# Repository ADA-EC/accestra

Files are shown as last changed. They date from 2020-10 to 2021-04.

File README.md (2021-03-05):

# Accestra
 Sistema de entrada/saída de membros na sala da ADA.

<h2> Descrição </h2>

O objetivo é desenvolver e instalar um sistema de abertura da porta por meio dos cartões USP, a partir da comunicação em rádio frequência (RFID).
  
<h2> Tencologias Usadas </h2>

Para compor o sistema de acesso, foi utilizado um Arduino UNO, com planos de usarmos apenas o <b>ATmega</b>. A porta é equipada com um <b>leitor de RFID</b> e um <b>botão</b> interno, enquanto a tranca será substituída por uma <b>fechadura elétrica</b> comum, acionada por um sinal elétrico enviado pelo sistema. Haverá ainda um <b>buzzer</b> para alertas sonoros e um <b>LED vermelho e outro verde</b> para indicação do estado.<br><br>
Na programação foram utilizadas as bibliotecas <b>SPI</b> e <b>MFRC522</b>

<h2> Protótipo </h2>

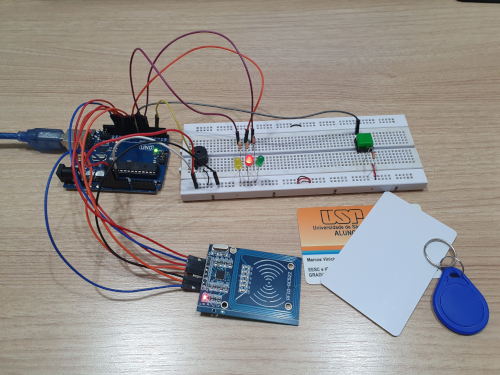
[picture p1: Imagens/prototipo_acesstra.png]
aaa


<h2> Manual do Sistema </h2>

Um manual do sistema, contendo informações detalhadas sobre o código e sobre como operar estará disponível neste repostório 

<h2>Membros</h2>
<ul>
 <li>Érika Hortência</li>
 <li>Fernando Rosalini Calaza</li>
 <li>Marcos Pietrucci</li>
</ul>
<h2>Agradecimentos</h2>
<ul>
 <li>Alexandre Batistella Bellas</li>
 <li>Bruno Coulturato pelas contribuições no desenvolvimento da PCB</li>

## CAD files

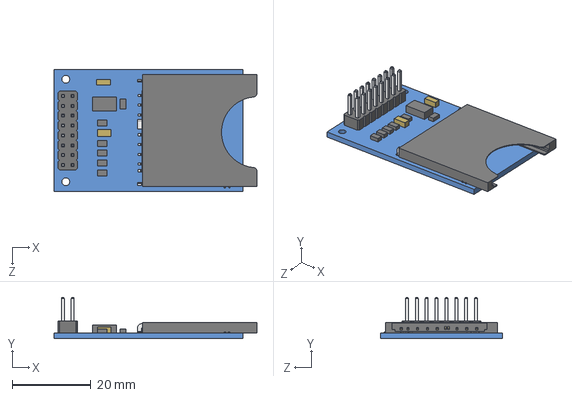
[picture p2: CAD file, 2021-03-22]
PCB/Componentes 3D/SD Card Module Arduino.STEP
51.5 x 10.5 x 31.0 mm
SD Card Module-part
SD socket

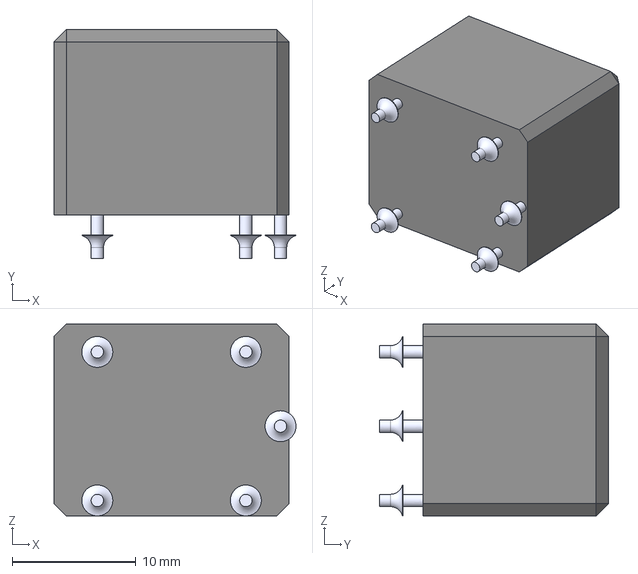
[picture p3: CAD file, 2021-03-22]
PCB/Componentes 3D/Relais HLS8L-DC3V-S-C.step
19.5 x 18.5 x 15.5 mm

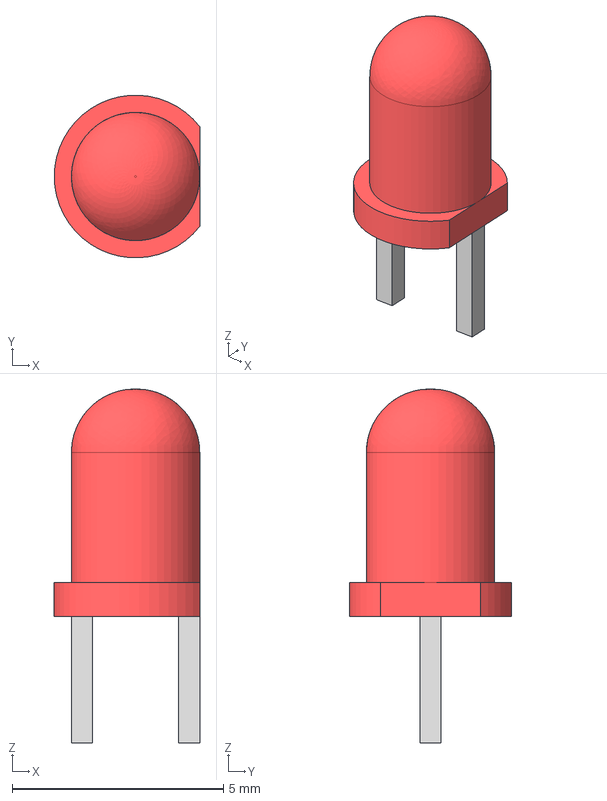
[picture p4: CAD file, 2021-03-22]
PCB/Componentes 3D/LED 3mm Red 3mm Leads.step
3.45 x 3.85 x 8.38 mm
LEDBody
Lead1Body
Lead2Body

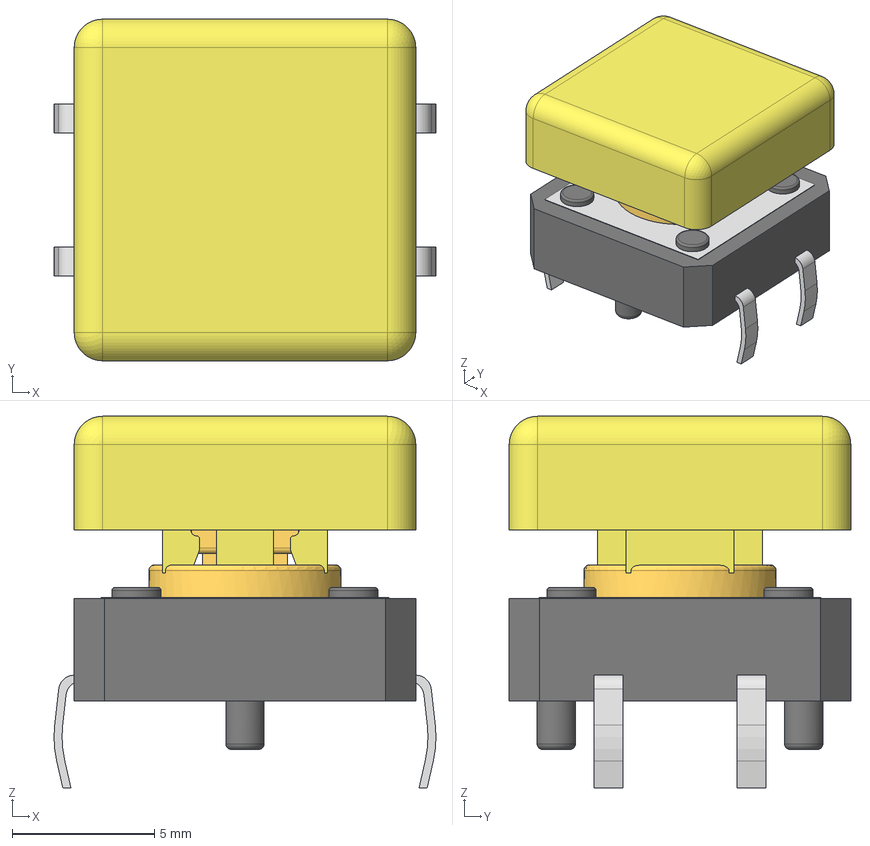
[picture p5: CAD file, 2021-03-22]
PCB/Componentes 3D/botao.stp
13.4 x 12.0 x 13.0 mm

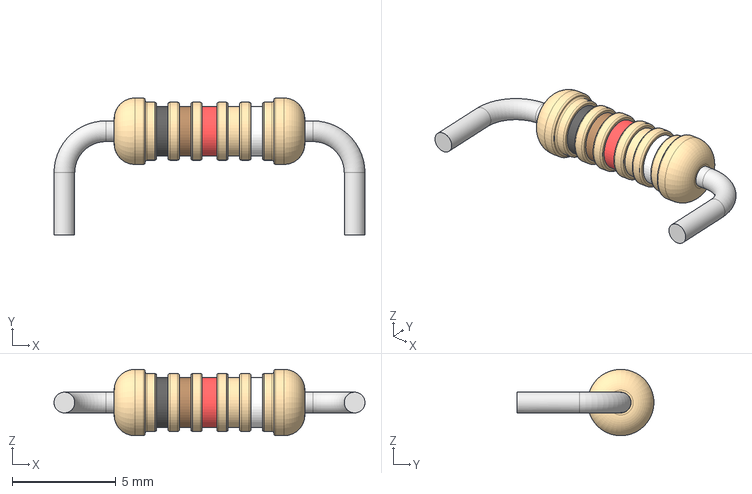
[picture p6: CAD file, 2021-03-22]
PCB/Componentes 3D/Resistor.step
15.0 x 6.60 x 3.20 mm

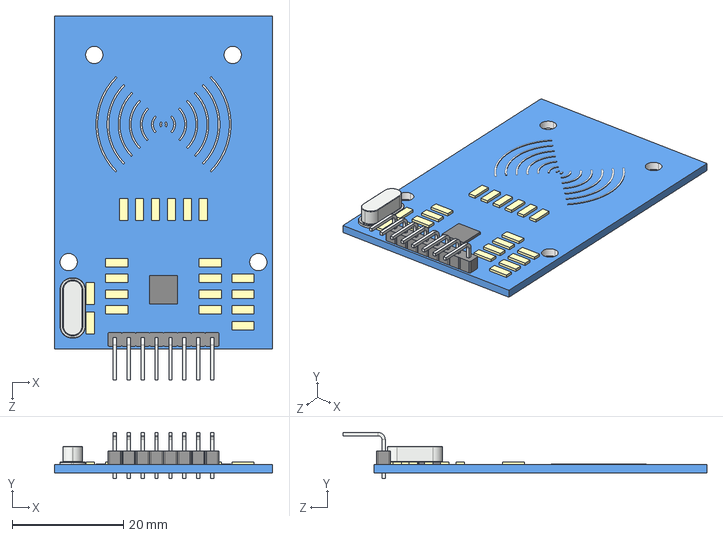
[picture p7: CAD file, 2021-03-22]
PCB/Componentes 3D/RC522.STEP
39.2 x 8.30 x 65.5 mm

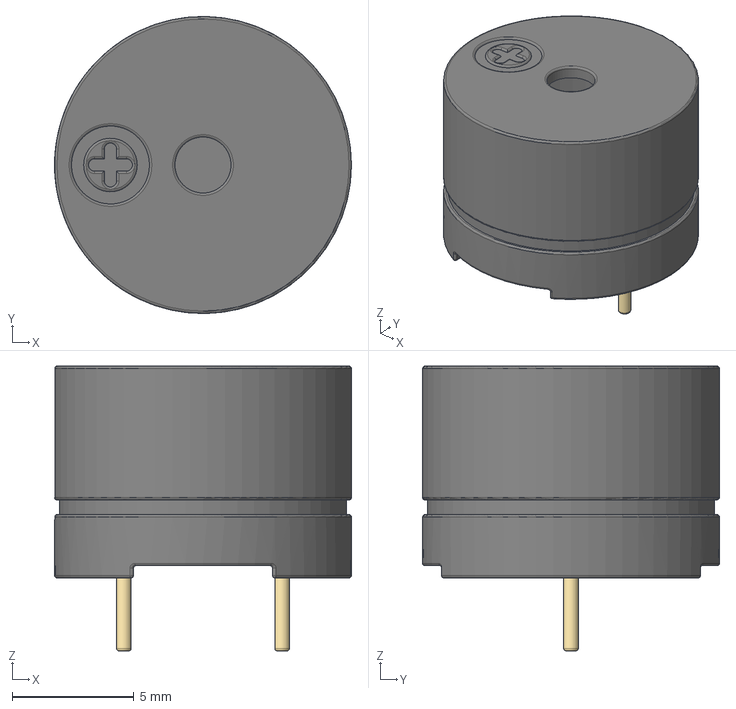
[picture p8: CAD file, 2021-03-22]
PCB/Componentes 3D/buzzer.stp
12.2 x 12.2 x 11.7 mm

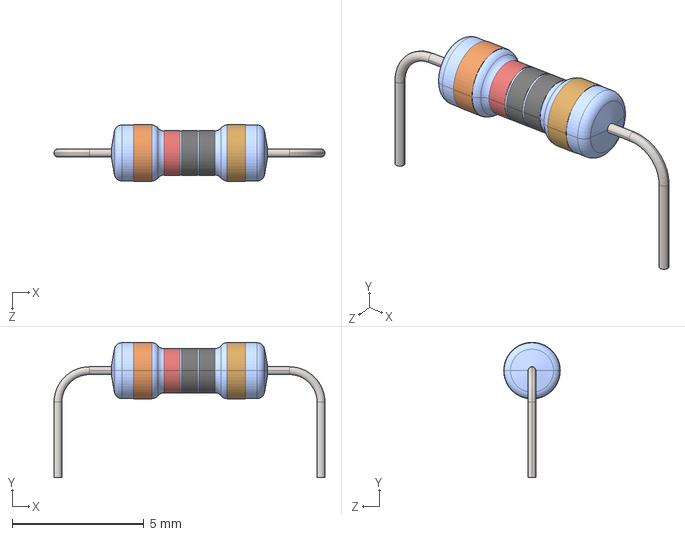
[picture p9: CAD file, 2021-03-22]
PCB/Componentes 3D/axial resistor 6mm.STEP
10.3 x 5.14 x 2.15 mm

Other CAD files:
PCB/Componentes 3D/NanoV3 v4.f3d

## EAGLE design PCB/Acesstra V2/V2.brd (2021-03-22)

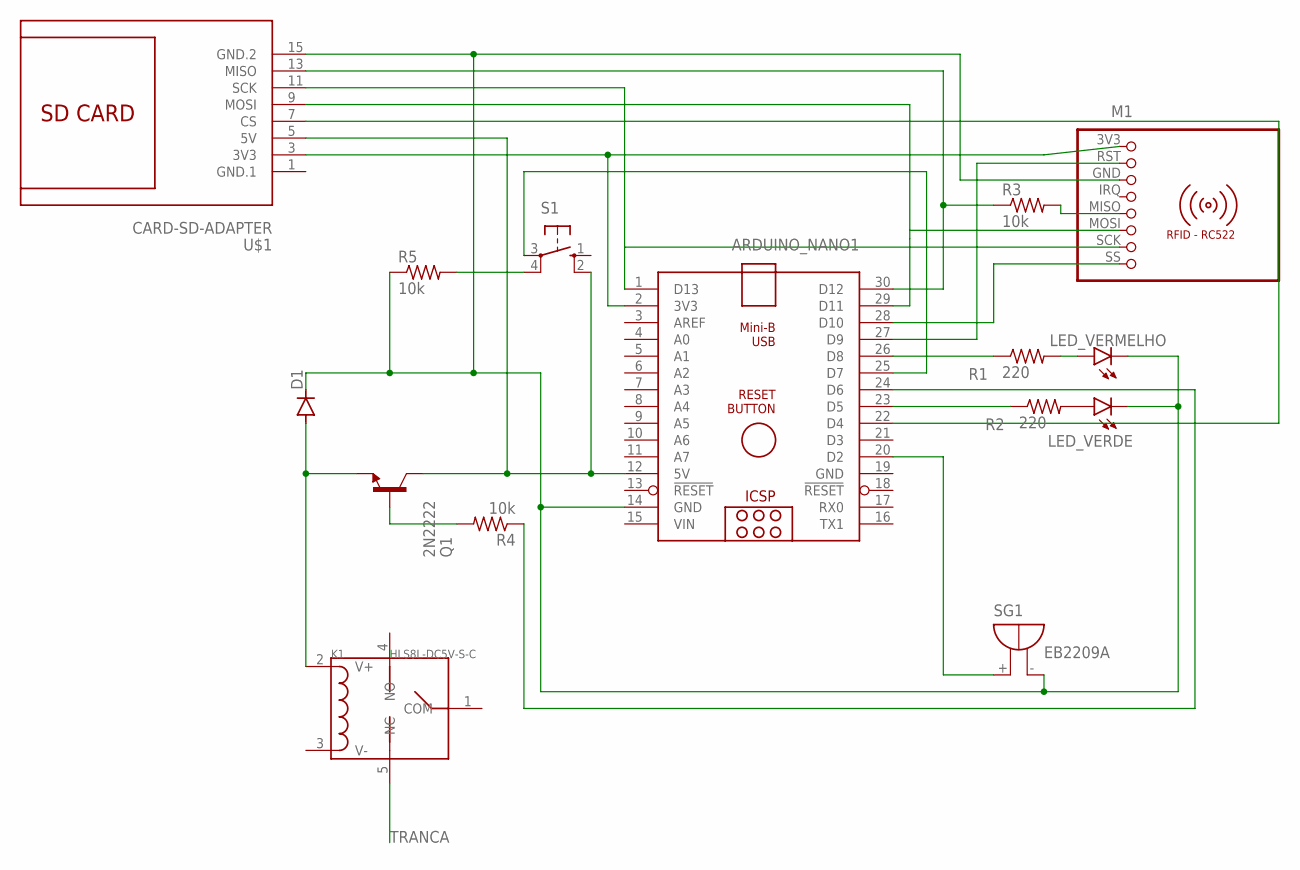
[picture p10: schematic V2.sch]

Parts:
ARDUINO_NANO1: ARDUINO_NANO
D1: 1N4148DO35-10; DO35-10
K1: HLS8L-DC5V-S-C; REY5-19.0X15.0X15.0MM
LED_VERDE: -LED; LED5
LED_VERMELHO: -LED; LED5
M1: RFID-RC522
Q1: 2N2222; TO92-CBE
R1, R2: 220; 0204/5
R3, R4, R5: 10k; 0204/5
S1: 10-XX; B3F-10XX
SG1: EB2209A
U$1: CARD-SD-ADAPTER

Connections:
GND: ARDUINO_NANO1.19 (GND)
GND.1: U$1.1 (GND.1)
unnamed: ARDUINO_NANO1.20 (D2), SG1.+
unnamed: LED_VERMELHO.ANODE, R1.2
unnamed: LED_VERDE.ANODE, R2.2
unnamed: ARDUINO_NANO1.26 (D8), R1.1
unnamed: ARDUINO_NANO1.23 (D5), R2.1
unnamed: ARDUINO_NANO1.24 (D6), R4.1
unnamed: D1.A, K1.2 (V+), Q1.E
unnamed: Q1.B, R4.2
unnamed: ARDUINO_NANO1.14 (GND), D1.C, LED_VERDE.CATHODE, LED_VERMELHO.CATHODE, M1.GND (3), R5.1, SG1.-, U$1.15 (GND.2)
unnamed: ARDUINO_NANO1.12 (5V), Q1.C, S1.2 (S1), U$1.5 (5V)
unnamed: ARDUINO_NANO1.25 (D7), S1.3
unnamed: ARDUINO_NANO1.2 (3V3), M1.3V3 (1), U$1.3 (3V3)
unnamed: R5.2, S1.4 (P1)
unnamed: ARDUINO_NANO1.27 (D9), M1.RST (2)
unnamed: M1.MISO (5), R3.2
unnamed: ARDUINO_NANO1.30 (D12), R3.1, U$1.13 (MISO)
unnamed: ARDUINO_NANO1.29 (D11), M1.MOSI (6), U$1.9 (MOSI)
unnamed: ARDUINO_NANO1.22 (D4), U$1.7 (CS)
unnamed: ARDUINO_NANO1.28 (D10), M1.SS (8)
unnamed: ARDUINO_NANO1.1 (D13), M1.SCK (7), U$1.11 (SCK)
TRANCA: K1.5 (NC)
VIN: ARDUINO_NANO1.15 (VIN)

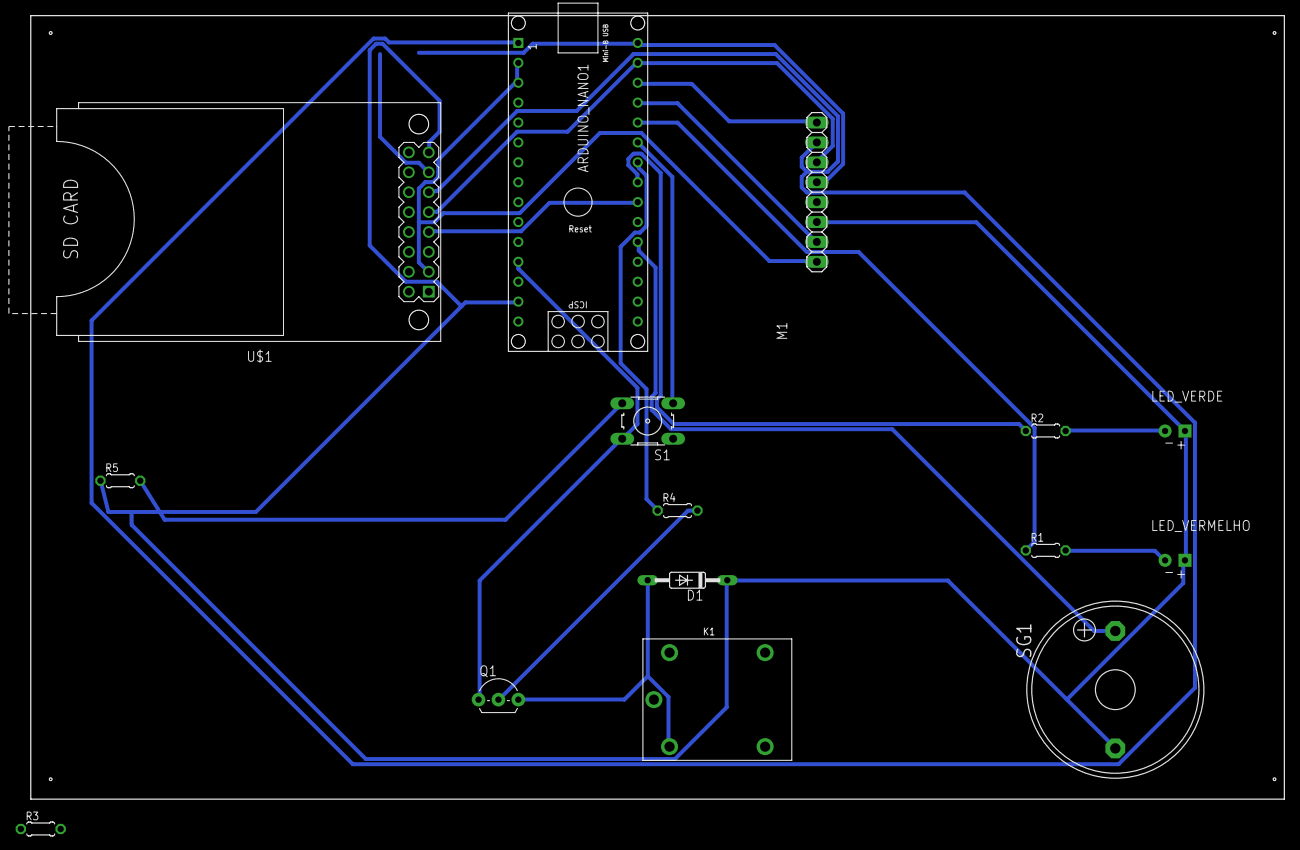
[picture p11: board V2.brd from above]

Board: 2 copper layers, 160.0 x 100.0 mm, 15 parts (0 on the bottom side), 20 nets.

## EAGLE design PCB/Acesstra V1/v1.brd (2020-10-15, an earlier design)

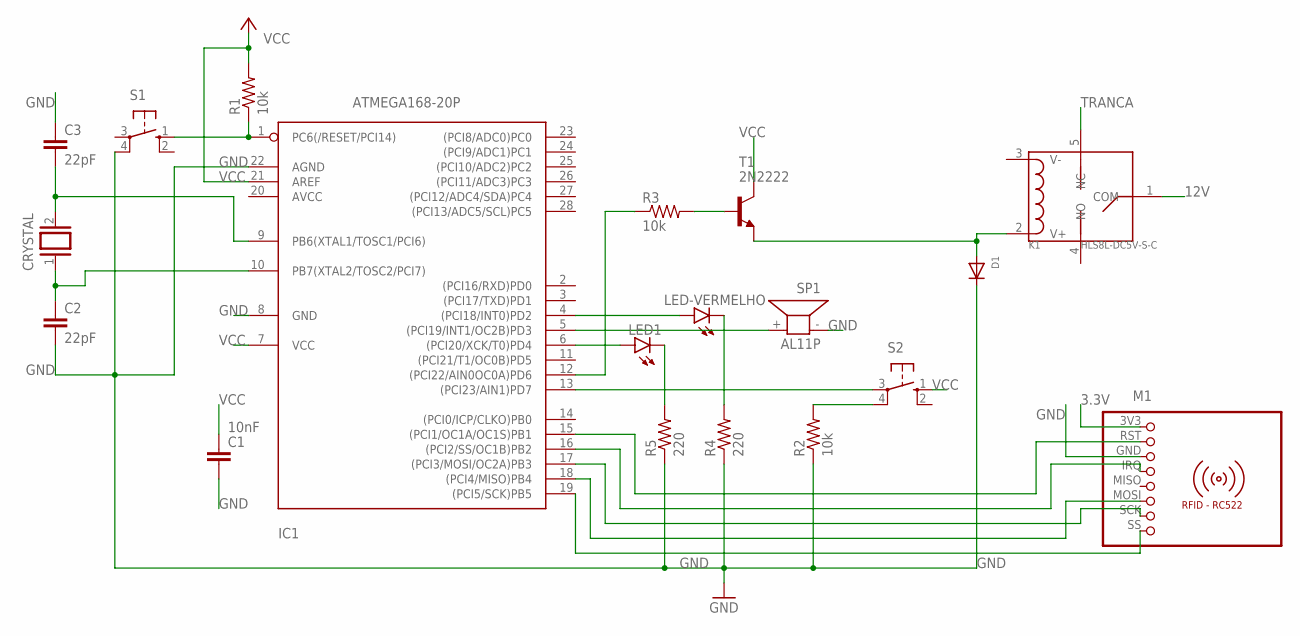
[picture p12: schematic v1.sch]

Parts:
C1: 10nF; C025-025X050
C2, C3: 22pF; C025-025X050
CRYSTAL: XTAL/S; QS
D1: DIODEDO-1N4148; DO-1N4148
IC1: ATMEGA168-20P; DIL28-3
K1: HLS8L-DC5V-S-C; REY5-19.0X15.0X15.0MM
LED1: LED5MM
LED-VERMELHO: LED5MM
M1: RFID-RC522
R1, R2, R3: 10k; 0204/7
R4, R5: 220; 0204/7
S1, S2: 10-XX; B3F-10XX
SP1: AL11P
T1: 2N2222; TO92-EBC-OVAL

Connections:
3.3V: M1.3V3 (1)
12V: K1.1 (COM)
GND: C1.2, C2.2, C3.1, D1.C, IC1.8 (GND), IC1.22 (AGND), M1.GND (3), R2.1, R4.1, R5.1, S1.4 (P1), SP1.- (1)
unnamed: IC1.1 (PC6(/RESET/PCI14)), R1.1, S1.1 (S)
unnamed: IC1.4 ((PCI18/INT0)PD2), LED-VERMELHO.A
unnamed: LED-VERMELHO.K (C), R4.2
unnamed: IC1.6 ((PCI20/XCK/T0)PD4), LED1.A
unnamed: LED1.K (C), R5.2
unnamed: IC1.5 ((PCI19/INT1/OC2B)PD3), SP1.+ (2)
unnamed: IC1.13 ((PCI23/AIN1)PD7), S2.3
unnamed: R2.2, S2.4 (P1)
unnamed: IC1.12 ((PCI22/AIN0OC0A)PD6), R3.1
unnamed: R3.2, T1.B
unnamed: D1.A, K1.2 (V+), T1.E
unnamed: C3.2, CRYSTAL.2, IC1.9 (PB6(XTAL1/TOSC1/PCI6))
unnamed: C2.1, CRYSTAL.1, IC1.10 (PB7(XTAL2/TOSC2/PCI7))
unnamed: IC1.15 ((PCI1/OC1A/OC1S)PB1), M1.RST (2)
unnamed: IC1.16 ((PCI2/SS/OC1B)PB2), M1.IRQ (4)
unnamed: IC1.17 ((PCI3/MOSI/OC2A)PB3), M1.SCK (7)
unnamed: IC1.18 ((PCI4/MISO)PB4), M1.MOSI (6)
unnamed: IC1.19 ((PCI5/SCK)PB5), M1.SS (8)
TRANCA: K1.5 (NC)
VCC: C1.1, IC1.7 (VCC), IC1.21 (AREF), R1.2, S2.1 (S), T1.C

Board: 2 copper layers, 19 parts (0 on the bottom side), 20 nets, no tracks yet.

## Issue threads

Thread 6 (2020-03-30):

Mudar a lógica de acionamento dos botões

Marcos-Pietrucci, 2020-03-30:
Pull-UP/Down - Faz diferença para o consumo no ATmega

Marcos-Pietrucci, 2020-04-03:
@FernandoCalaza Você pode me ajudar nisso, se tiver tempo? Sinta-se livre pra criar uma branch e fazer um pull-request, ou simplesmente me explicar melhor aqui o que deve ser feito

Marcos-Pietrucci, 2021-01-09:
Após pesquisa, a lógica do botão foi alterada. A entrada digital do botão permanece em nível lógico baixo, e assim que é detectado nível lógico alto, é feita abertura da porta.

Poupa-se, assim, energia elétrica (apesar de ser uma quantidade bem pequena)

Closed 2021-01-09.

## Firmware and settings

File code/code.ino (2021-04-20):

#include <SPI.h>
#include <SD.h>
#include <MFRC522.h>
#define SS_SD           4  // Slave Select do cartão SD
#define SS_RFID         10 // Slave Select do RFID
#define RST_PIN         9  // Configurable, see typical pin layout above
#define led_verde       5  // Led que indica porta positivo
#define led_vermelho    8  // Led que indica porta negativo
#define porta           6  // Envia o sinal de abertura para a porta
#define but_in          7  // Botão interno que abre a porta
#define buzzerPin       2  // Pino do buzzer que emite alertas sonoros

// --- Objetos do RFID --- //
MFRC522 mfrc522(SS_RFID, RST_PIN);   // Create MFRC522 instance

// --- Objetos do SD --- //
File arquivo;

// Struct dos membros
typedef struct memb
{
  byte codigo[4];
}Membro;

//UID que será lido na loop
byte UID_loop[4];

//UID do cartão de cadastro
byte UID_cadastro[4] = {146, 129, 82, 28};

//UID do cartão de descadastro
byte UID_descadastro[4] = {0, 0, 0, 0};

//0 para fechado, 1 para aberto
int estado_porta = 0; 

//Emite alerta sonoro de positivo
void positivo()
{
  tone(buzzerPin, 440, 400);
  delay(200);
  noTone(buzzerPin);
  tone(buzzerPin, 523, 400);
  delay(400);
  noTone(buzzerPin);
}

//Emite alerta sonoro de negativo
void negativo()
{
  tone(buzzerPin, 440, 400);
  delay(200);
  noTone(buzzerPin);
  tone(buzzerPin, 349, 400);
  delay(400);
  noTone(buzzerPin);
}

//Ajusta os leds para o estado atual da porta
void ajusta_led() 
{
  //Se estiver fechado
  if (!estado_porta)
  {
    digitalWrite(led_verde, LOW);
    digitalWrite(led_vermelho, HIGH);
  }
  else  //Se estiver aberto
  {
    digitalWrite(led_verde, HIGH);
    digitalWrite(led_vermelho, LOW);
  }
}

//Função que abre a porta - envia sinal elétrico para a tranca
void abre_porta()
{
  //Ativar a trava elétrica
  digitalWrite(porta, HIGH); 
  
  //O melhor tempo de delay deve ser testado
  delay(300);                
  digitalWrite(porta, LOW); 

  //Alterar os Leds
  estado_porta = 1;
  ajusta_led();
  positivo();
  delay(1000);

  //Alterar os Leds
  estado_porta = 0;
  ajusta_led();
}

//Função que lê um cartão USP e o cadastra no SD
void cadastra_membro()
{
  //Importante para não recadastrar o próprio cartão admin
  delay(1000);
  
  int estado_led = HIGH;
  int i;

  //Enquanto ainda não aproximar o cartão
  while ( ! mfrc522.PICC_IsNewCardPresent() || ! mfrc522.PICC_ReadCardSerial())
  {
    digitalWrite(led_verde, estado_led);
    digitalWrite(led_vermelho, estado_led);

    //Blinkar o LED
    estado_led = !estado_led; 

    //Som para indicar estado de cadastro
    tone(buzzerPin, 349, 400);
    delay(100);
    tone(buzzerPin, 349, 400);
    noTone(buzzerPin);
    delay(300);
  }
  
  //***************** Bloco de detecção de cartões  ***********//
  byte UID_lido[4];
  MFRC522::PICC_Type piccType = mfrc522.PICC_GetType(mfrc522.uid.sak);

  //Verifica se o cartão é do tipo válido
  if (piccType != MFRC522::PICC_TYPE_MIFARE_MINI &&  
    piccType != MFRC522::PICC_TYPE_MIFARE_1K &&
    piccType != MFRC522::PICC_TYPE_MIFARE_4K) 
  {
    negativo();
    ajusta_led();
    return;
  }

  //Armazena o UID lido
  for (byte j = 0; j < 4; j++) {
    UID_lido[j] = mfrc522.uid.uidByte[j];
  }

  //Desativa o RFID e ativa o SD
  digitalWrite(SS_RFID, HIGH);
  digitalWrite(SS_SD, LOW);
  delay(3);
  
  //------------------ Inserir o novo membro no cartão SD --------/
  if (!SD.begin(SS_SD))
  {
    erro();
  }
  
  //Abre o arquivo de membros
  arquivo = SD.open("membros.bin", FILE_WRITE); 
  
  if (arquivo) 
  {
    //Escreve os 4 bytes do UID lido
    arquivo.write(UID_lido, 4);
    arquivo.close();
  } 
  else 
  {
    erro();
  }

  //Desativa o SD e ativa o RFID
  digitalWrite(SS_RFID, LOW);
  digitalWrite(SS_SD, HIGH);
  delay(3);
  
  ///***************** Fim do bloco de cadastro de membros *******/
  ajusta_led();
  delay(1500);
}

//Função que verifica se o UID lido corresponde a algum cadastrado
boolean busca_membro(byte *UID_lido)
{
  int i;
  Membro mem;

  //Desativa o RFID e ativa o SD
  digitalWrite(SS_RFID, HIGH);
  digitalWrite(SS_SD, LOW);
  delay(3);
  
  //Abre o arquivo de membros
  arquivo = SD.open("membros.bin", FILE_READ);
  
  if(!arquivo)
    erro();

  for(i = 0; i < arquivo.size() ; i += 4)
  {
    //Lê arquivo os bytes do cartão SD
    arquivo.read(mem.codigo, 4);

    //Compara o UID lido com o membro cadastrado
    if(memcmp(UID_lido, mem.codigo, 4) == 0)
    {
      return true;
    }
  } 

  //Desativa o SD e ativa o RFID
  digitalWrite(SS_RFID, LOW);
  digitalWrite(SS_SD, HIGH);
  delay(3);

  return false; 
}

//Função que lê um cartão e o descadastra caso encontre-o
void deleta_membro()
{
  delay(1000); //Importante para não recadastrar o próprio cartão admin
  int estado_led = HIGH;
  int i;
  
  //Enquanto ainda não aproximar o cartão
  while ( ! mfrc522.PICC_IsNewCardPresent() || ! mfrc522.PICC_ReadCardSerial())
  {
    digitalWrite(led_verde, estado_led);
    digitalWrite(led_vermelho, estado_led);
    
    //Blinkar o LED
    estado_led = !estado_led; 

    //Alerta sonoro de descadastro
    tone(buzzerPin, 349, 400);
    delay(100);
    tone(buzzerPin, 523, 400);
    noTone(buzzerPin);
    delay(300);
  }
  
  //***************** Bloco de detecção de cartões ***********//
  
  byte UID_lido[4];
  MFRC522::PICC_Type piccType = mfrc522.PICC_GetType(mfrc522.uid.sak);

  //Verifica se o cartão é do tipo válido
  if (piccType != MFRC522::PICC_TYPE_MIFARE_MINI &&  
    piccType != MFRC522::PICC_TYPE_MIFARE_1K &&
    piccType != MFRC522::PICC_TYPE_MIFARE_4K) 
  {
    negativo();
    ajusta_led();
    return;
  }

  //Armazena o UID lido
  for (byte j = 0; j < 4; j++) {
    UID_lido[j] = mfrc522.uid.uidByte[j];
  }

  //Ativa o SD e desativa o cartão RFID
  digitalWrite(SS_RFID, HIGH);
  digitalWrite(SS_SD, LOW);

  //---- Percorrer o cartão SD e deletar o membro lógicamente ---- //
  byte vetorNulo[4] = {0,0,0,0};
  int flag = 0;
  Membro mem;
 
  //Abre o arquivo de membros
  arquivo = SD.open("membros.bin", O_WRITE | O_READ);

  if(!arquivo)
    erro();

  for(i = 0; i < arquivo.size() ; i += 4)
  {
    //Lê arquivo os bytes do cartão SD
    arquivo.read(mem.codigo, 4);

    //Compara o UID lido com o membro cadastrado
    if(memcmp(UID_lido, mem.codigo, sizeof(UID_lido)) == 0)
    { 
      //Volta o ponteiro 4 bytes atrás
      arquivo.seek(arquivo.position() - 4);

      //Escreve valor nulo no registro
      arquivo.write(vetorNulo, 4);

      //Indica que houve o descadastro
      flag = 1;
      
      break;
    }
  }   
  
  arquivo.close();

  //Se não houve descadastro, emitir alerta negativo
  if(!flag)
  {
    negativo();
  }
  
  //Ativa o RFID e desativa o cartão SD
  digitalWrite(SS_RFID, LOW);
  digitalWrite(SS_SD, HIGH);

  ///***************** Fim do bloco de descadastro de membros *******/
  ajusta_led();
  delay(1500);
}

//Função que emite um alerta sonoro e visual de erro
void erro()
{
  //O usuário deve corrigir o problema e resetar o sistema
  digitalWrite(led_verde, HIGH);
  digitalWrite(led_vermelho, HIGH);   
  
  while(1)
  {    
    tone(buzzerPin, 400, 200);
    delay(300);  
    noTone(buzzerPin);
    delay(300);                                                                                                                                                                                                                                                                                                          
  }
}

void setup()
{
  // ----------- Preparar os pinos ----------- //
  pinMode(porta, OUTPUT);         
  pinMode(led_verde, OUTPUT);    
  pinMode(led_vermelho, OUTPUT);  

  pinMode(SS_RFID, OUTPUT);
  pinMode(SS_SD, OUTPUT);
  
  Serial.begin(9600);           
  SPI.begin();                   
  ajusta_led();

  //Desativa o RFID
  digitalWrite(SS_RFID, HIGH);
  
  // ------------- Cartão SD --------------- //
  //Verifica se o cartão está funcionando
  if (!SD.begin(SS_SD)) 
  {
    erro();
  }

  //Ativa o RFID e desativa o cartão SD
  digitalWrite(SS_RFID, LOW);
  digitalWrite(SS_SD, HIGH);

  //Inicia o MFRC522
  mfrc522.PCD_Init();
} 

void loop()
{
  //Verifica se apertaram o botão interno
  if (digitalRead(but_in)) 
  {
    //Não fazer nada enquanto o botão estiver pressionado
    while (digitalRead(but_in) == HIGH) {
      ;
    }

    //Botão foi solto, abrir a porta
    abre_porta();
  }

  //***************** Bloco de detecção de cartões que serão aproximados **************/
  
  //Verifica se tem cartão presente
  if ( ! mfrc522.PICC_IsNewCardPresent()) {
    return;
  }
  
  if ( ! mfrc522.PICC_ReadCardSerial()) {
    return;
  }

  //Cria um objeto leitor
  MFRC522::PICC_Type piccType = mfrc522.PICC_GetType(mfrc522.uid.sak);
    
  // Verifica se o cartão é do tipo válido
  if (piccType != MFRC522::PICC_TYPE_MIFARE_MINI &&  
    piccType != MFRC522::PICC_TYPE_MIFARE_1K &&
    piccType != MFRC522::PICC_TYPE_MIFARE_4K) 
  {
    negativo();
    return;
  }

  //Vetor que armazenará o UID
  byte UID_lido[4];
  
  // Armazena o UID lido
  for (byte i = 0; i < 4; i++)
  {
    UID_loop[i] = mfrc522.uid.uidByte[i];
  }
  
  ///******************** Processar o UID lido *****************************/

  //Verificar se o UID lido é o mestre
  if(memcmp(UID_loop, UID_cadastro, sizeof(UID_loop)) == 0)
  {
    //UID lido é o mestre, iniciar cadastro
    cadastra_membro();
  }
  //Verificar se o UID lido é o de descadastro
  else if(memcmp(UID_loop, UID_descadastro, sizeof(UID_loop)) == 0)
  {
    //UID lido é o de descadastro
    deleta_membro();
  }
  //Verificar se o UID lido é de algum membro
  else if(busca_membro(UID_loop))
  {
    //Positivo: Abrir a porta
    abre_porta();
  }
  else
  {
    //Negativo: Cartão não cadastrado
    negativo();
  }
  
}

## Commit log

2019-11-09 Add files via upload
    O código é capaz de:
    -Indicar por meio de Leds se a porta está fechada ou aberta;
    -Abrir e fechar a porta, baseado na leitura de tags e cartões FRID dos membros. Se a tag ou cartão não pertencer a um membro, o acesso é negado (as interações são feitas via monitor Serial);
    -Por meio de botões auxiliares abrir e fechar a porta;
    -Registrar novos membros no sistema.
2019-12-18 Mudanças iniciais - Retirada de tudo que lida com o armazenamento dos números permitidos e com dados dos membros
2019-12-18 Retoques: adição de comentários e remoção de comandos inúteis
2020-01-06 Update - Melhorias no código
    - O pino 10 já estava em uso
    - Diminui a quantidade de bips ao fechar a porta
2020-01-06 Mudanças nos tons sonoros & Adição de som no modo de cadastro
2020-03-31 Ajustando o código para a trava elétrica
2020-04-23 Retirando o botão externo, que está inutilizado
2020-10-15 Adicionando primeiro esquematico - EAGLE
    [v1.brd, v1.sch]
2021-01-07 Adicionando leitura de cartões USP! Além disso toda a lógica do programa foi alterada, aceitando TAGS, cartões USP ou qualquer outro dispositivo RFID compatível
2021-03-05 Adição de comentários e pequenos ajustes após GC
2021-03-16 Adicionando alerta sonoro e visual de erro
2021-03-20 Ajustando a mensagem de erro do SD
2021-03-22 Upload da segunda versão da PCB
    [LED 3mm Red 3mm Leads.step, NanoV3 v4.f3d, RC522.STEP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]
2021-03-22 Ajustes na PCB
    [V2.brd, V2.sch]
2021-03-22 Ajuste da PCB
    [V2.brd, V2.sch]
2021-04-09 Ajustes no aviso sonoro de erro. Agora é mais singular do que o aviso de cadastro/descadastro
2021-04-20 Removendo duplicação de aviso sonoro

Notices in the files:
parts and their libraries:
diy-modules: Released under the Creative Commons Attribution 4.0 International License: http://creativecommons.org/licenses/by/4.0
